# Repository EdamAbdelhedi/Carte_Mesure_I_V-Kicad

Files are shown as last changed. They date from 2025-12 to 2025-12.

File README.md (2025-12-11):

La carte de mesures électriques a été réalisée pendant mon stage d’ingénieur, du 18 juin au 27 juillet 2024, au sein du Laboratoire des Systèmes Électriques de l’ENIT, sous l’encadrement de monsieur Mohamed Wissem Naouar.

Cette carte se compose de deux blocs :

Bloc de mesure de courant

Bloc de mesure de tension

****Pour le premier bloc, nous avons utilisé le capteur LA55-P, permettant la mesure de courants jusqu'à 50 A.
Ce bloc est composé de trois étages :

Capteur de courant LA55-P avec sa résistance de mesure

Amplificateur passe-bas inverseur

Soustracteur différentiel (permet d’ajouter un décalage supplémentaire de 1,5 V au signal d’entrée)

Bloc de mesure de tension

****Pour le deuxième bloc, nous avons utilisé le capteur LV25-P, permettant la mesure de tensions jusqu'à ±500 V.
Ce bloc est composé de trois étages :

Capteur de tension LV25-P avec sa résistance de mesure

Suiveur pour assurer une adaptation d’impédance

Filtre passe-bas inverseur (permet de supprimer les bruits électriques et les interférences pouvant affecter la mesure de tension)

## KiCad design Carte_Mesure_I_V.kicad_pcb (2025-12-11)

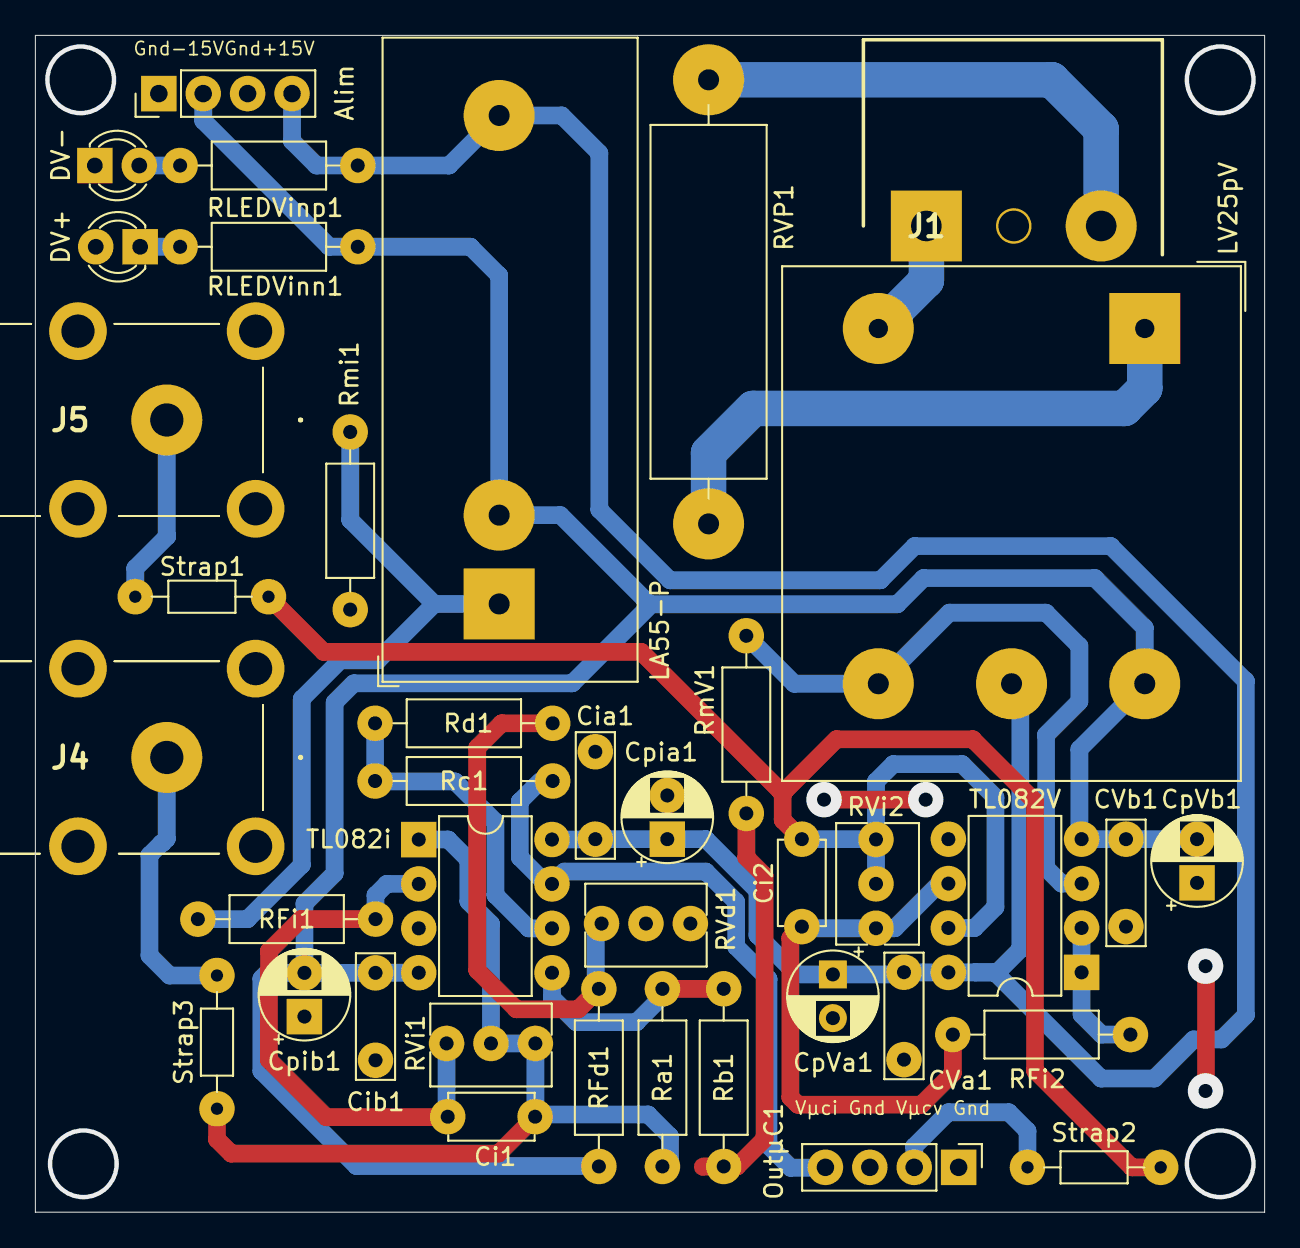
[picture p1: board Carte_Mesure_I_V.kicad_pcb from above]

Board: 2 copper layers, 70.3 x 67.3 mm, 39 parts (0 on the bottom side), 22 nets.

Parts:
Alim: Alim; PinHeader_1x04_P2.54mm_Vertical
CVa1: 100n; C_Rect_L7.0mm_W2.0mm_P5.00mm
CVb1: 100n; C_Rect_L7.0mm_W2.0mm_P5.00mm
Ci1: 220p; C_Disc_D4.7mm_W2.5mm_P5.00mm
Ci2: 4.7n; C_Disc_D4.7mm_W2.5mm_P5.00mm
Cia1: 100n; C_Rect_L7.0mm_W2.0mm_P5.00mm
Cib1: 100n; C_Rect_L7.0mm_W2.0mm_P5.00mm
CpVa1: 1µ; CP_Radial_D5.0mm_P2.50mm
CpVb1: 1µ; CP_Radial_D5.0mm_P2.50mm
Cpia1: 1µ; CP_Radial_D5.0mm_P2.50mm
Cpib1: 1µ; CP_Radial_D5.0mm_P2.50mm
DV+: LED; LED_D3.0mm
DV-: LED; LED_D3.0mm
J1: BorV; 2350513-3
J4: BNCi_osc; BNCLRPC140
J5: BNCV_osc; BNCLRPC140
LA55-P: LA55-P; LEM_LA25-P
LV25pV: LV25pV; LEM_LV25-P
OutµC1: OutµC; PinHeader_1x04_P2.54mm_Vertical
RFd1: 1k; R_Axial_DIN0207_L6.3mm_D2.5mm_P10.16mm_Horizontal
RFi1: 10k; R_Axial_DIN0207_L6.3mm_D2.5mm_P10.16mm_Horizontal
RFi2: 4.7k; R_Axial_DIN0207_L6.3mm_D2.5mm_P10.16mm_Horizontal
RLEDVinn1: 10k; R_Axial_DIN0207_L6.3mm_D2.5mm_P10.16mm_Horizontal
RLEDVinp1: 10k; R_Axial_DIN0207_L6.3mm_D2.5mm_P10.16mm_Horizontal
RVP1: 47k-5W; R_Axial_Power_L20.0mm_W6.4mm_P25.40mm
RVd1: 0.2k; Potentiometer_Bourns_3266Y_Vertical
RVi1, RVi2: 10k; Potentiometer_Bourns_3266Y_Vertical
Ra1: 20k; R_Axial_DIN0207_L6.3mm_D2.5mm_P10.16mm_Horizontal
Rb1: 20k; R_Axial_DIN0207_L6.3mm_D2.5mm_P10.16mm_Horizontal
Rc1: 20k; R_Axial_DIN0207_L6.3mm_D2.5mm_P10.16mm_Horizontal
Rd1: 20k; R_Axial_DIN0207_L6.3mm_D2.5mm_P10.16mm_Horizontal
RmV1: 120; R_Axial_DIN0207_L6.3mm_D2.5mm_P10.16mm_Horizontal
Rmi1: 60; R_Axial_DIN0207_L6.3mm_D2.5mm_P10.16mm_Horizontal
Strap1, Strap2, Strap3: R_Axial_DIN0204_L3.6mm_D1.6mm_P7.62mm_Horizontal
TL082V: TL082V; DIP-8_W7.62mm
TL082i: TL082i; DIP-8_W7.62mm

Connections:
+15V: Alim.4, CVa1.1, Cia1.1, CpVa1.1, Cpia1.1, LA55-P.3 (+), LV25pV.5 (V+), RLEDVinp1.1, TL082V.8 (V+), TL082i.8 (V+)
-15V: Alim.2, CVb1.1, Cib1.1, CpVb1.2, Cpib1.2, LA55-P.2 (-), LV25pV.6 (V-), RFd1.1, RLEDVinn1.1, TL082V.4 (V-), TL082i.4 (V-)
GND: Alim.1, Alim.3, CVa1.2, CVb1.2, Cia1.2, Cib1.2, CpVa1.2, CpVb1.1, Cpia1.2, Cpib1.1, DV+.2 (A), DV-.1 (K), J4.2, J4.3, J4.4, J4.5, J5.2, J5.3, J5.4, J5.5, OutµC1.1, OutµC1.3, RVd1.1, RVd1.2, Rb1.2, RmV1.2, Rmi1.2, TL082V.5 (+), TL082i.3 (+)
unnamed: DV+.1 (K), RLEDVinn1.2
unnamed: DV-.2 (A), RLEDVinp1.2
unnamed: J1.3, RVP1.1
unnamed: J4.1, Strap3.2
unnamed: J5.1, Strap1.2
unnamed: OutµC1.2, Strap2.1
unnamed: RFd1.2, RVd1.3, Rc1.1
unnamed: LA55-P.1 (M), RFi1.1, Rmi1.1
unnamed: LV25pV.1 (HV+), RVP1.2
unnamed: J1.1, LV25pV.3 (HV-)
unnamed: LV25pV.4 (M), RmV1.1, TL082V.3 (+)
unnamed: RFi2.1, TL082V.1, TL082V.2 (-)
unnamed: Ci2.1, RFi2.2, RVi2.3, TL082V.6 (-)
unnamed: Ci1.1, RFi1.2, RVi1.3, TL082i.2 (-)
unnamed: Ra1.2, Rb1.1, TL082i.5 (+)
unnamed: Rc1.2, Rd1.1, TL082i.6 (-)
Vosc_i: Ci1.2, RVi1.1, RVi1.2, Ra1.1, Strap3.1, TL082i.1
Vosc_µc_V: Ci2.2, RVi2.1, RVi2.2, Strap1.1, Strap2.2, TL082V.7
Vµc_i: OutµC1.4, Rd1.2, TL082i.7
